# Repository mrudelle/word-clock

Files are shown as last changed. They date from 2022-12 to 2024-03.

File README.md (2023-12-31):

# Modular word-clock software for micropython

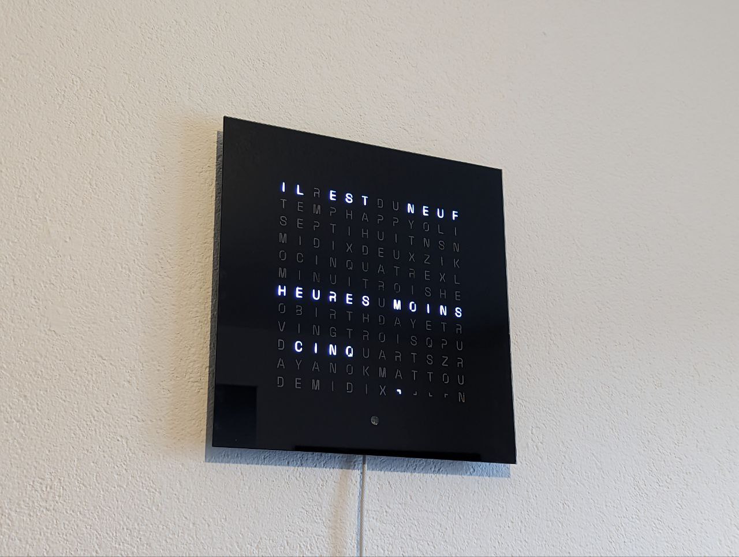
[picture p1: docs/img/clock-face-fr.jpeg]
Word clock


* Support the addition of new clock faces (other dimensions, language, layout,...). see `src/clock_face`
* Compatible with neopixel LED strips
* Custom designed PCB jumper to easily build the neopixel LED Matrix ([See /hardware/pcb_jumper](/hardware/pcb_jumper/))
* Light sensor based luminosity adjustment
* Create your own animations. see `src/rendering`
* Asynchronous implementation with asyncio

## Sample wiring with Pi Pico

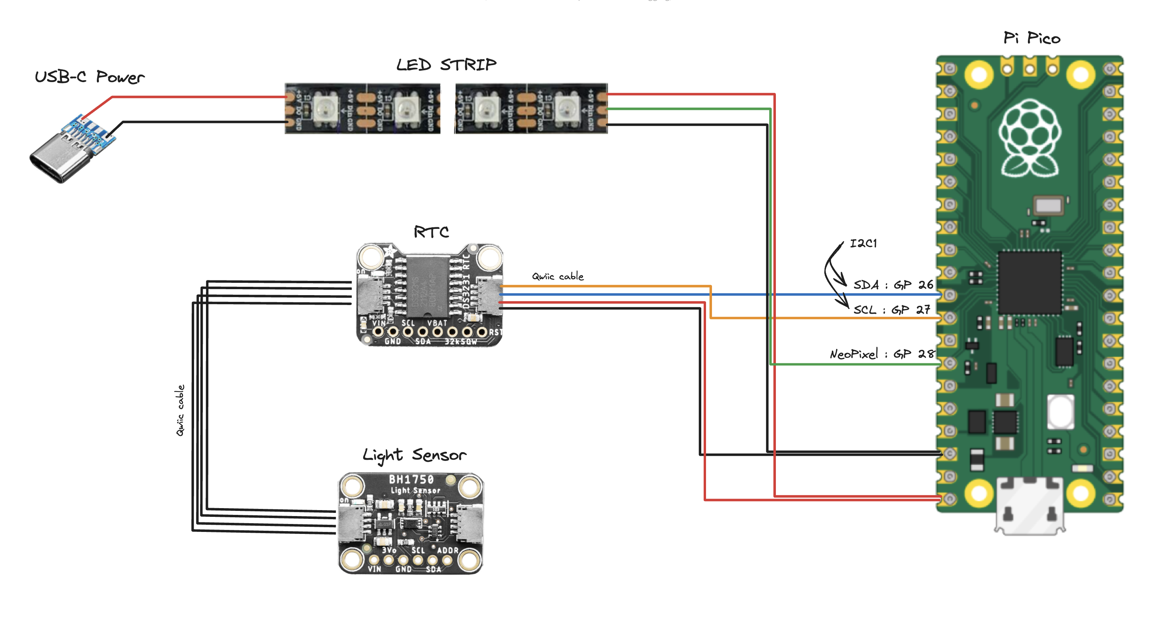
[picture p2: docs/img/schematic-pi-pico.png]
Word clock sample schematic with raspberry pi pico

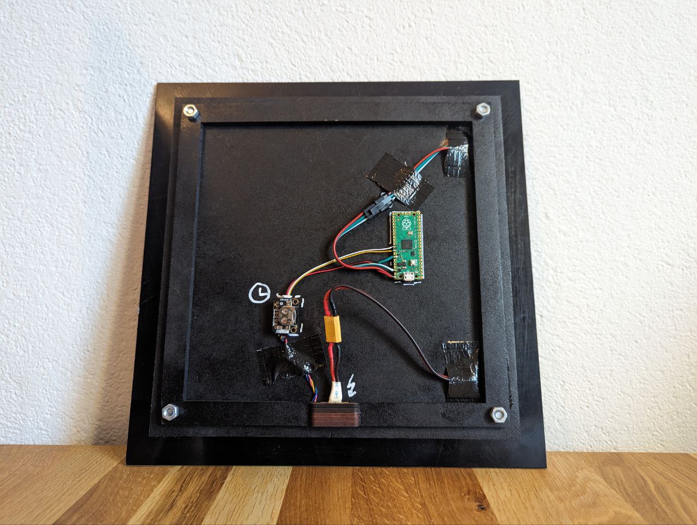
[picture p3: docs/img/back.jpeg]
Word clock wiring with raspberry pi pico

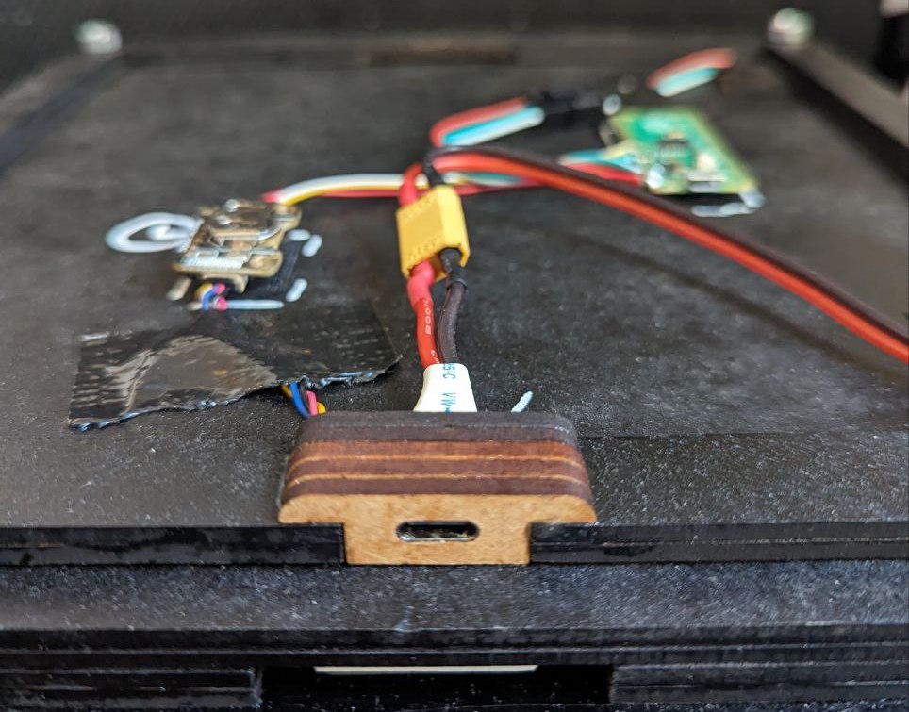
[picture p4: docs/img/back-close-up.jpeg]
Word clock usb socket


## Usage

### Install Requirements

```
python3 -m venv .venv
source .venv/bin/activate
pip3 install -r requirements-dev.txt
```

### Install code on rpi
Plug Raspbery Pi via USB,

```
mpremote cp -r src :
mpremote cp boot.py :.
mpremote cp main.py :.
```

Unplug and plug the clock to restart it.

### Set time

First, edit the time in `src/utils/set_date_time.py` so that it reflects the current time (plus a couple of seconds). Then run this command to set the time on the clock.

TODO: use the computer time to automatically set the clock time

```
mpremote run src/utils/set_date_time.py
```

### Dev

```
# run the main loop to catch any error
mpremote run main.py 
```

## Build

See [/hardware](/hardware/) for build infos and files

* Glass front with die-cut sticker on the back
* USB-C powered
* Frame laser cut in 4mm MDF
* Custom PCB board to wire the LED matrix

Font used for the clock face: [wordclock-stencil-mono](https://github.com/mrudelle/wordclock-stencil-mono)

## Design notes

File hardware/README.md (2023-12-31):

# Wordclock v2 Build

## BOM

* Raspberry pi pico
* RTC precision module DS3231 with stemma qt connectors (regular RTC modules like pcf8523 will drift by almost an hour per year)
* Light sensor BH1750 with stemma qt connectors
* 2 stemma qt connectors
* Neopixel led strip (eg. SK6812 or ws2814) 60 LED/m, 2.5m (important: not waterproof)
* USB-C breakout board
* Optional: XT30 or 60 connector
* 11 PCB jumper (or use 11*3 small cables) [See /hardware/pcb_jumper](pcb_jumper/)
* 3mm thick glass panel 30x30cm
* MDF (3mm) Board to cut all components
* 4x M6 bolts with cone-shaped head

## Build

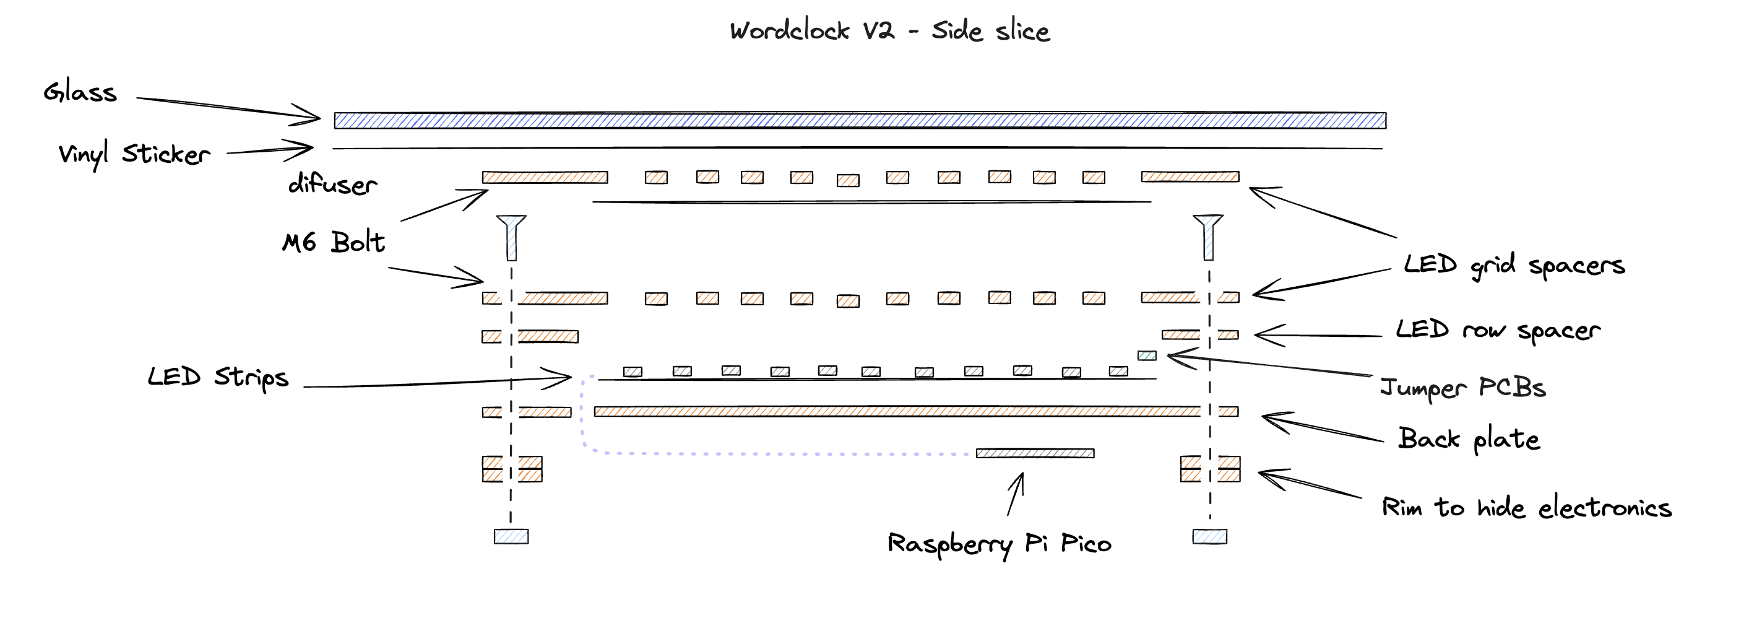
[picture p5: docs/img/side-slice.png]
Wordclock v2 side slice


The clock is made of a *glass panel* with a *die-cut vinyl sticker* on the back with the pattern of our clock. I ordered my glass panel from a glass shop nearby, prefer chamfered and polished edges. For the clock face I used this font [word-clock-stencil-mono](https://github.com/mrudelle/wordclock-stencil-mono). Pattern was cut on a cricut tracer. To apply the pattern I used the water technique and an credit card to squeeze all bubbles out. Longest part was taking out all the letters with a pair of tweezers (that's why the font is stencil).

On the vinyl is glued a lasercut MDF grid spacer. The vinyl was gently sanded to provide more grip for the glue.

A diffuser is placed on the spacer. I colored the diffuser with a black marker so that letters are stealth when not lit up. _Tip: mark the squares with a checker pattern to avoid the page to warp too much_

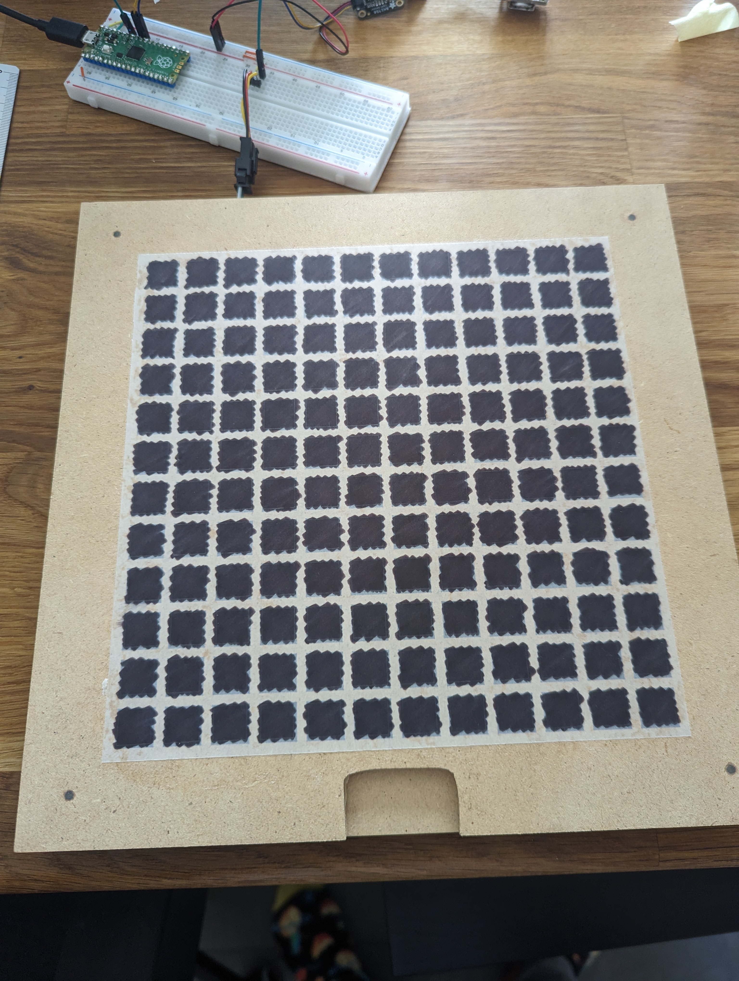
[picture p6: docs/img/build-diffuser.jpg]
Wordclock v2 diffuser


Another MDF grid spacer is placed on top (glued) with 4 cone-shaped head m6 screws. The screw will help hold the various layers together. The MDF grid spacer m6 holes are chamfered to hold on to the screws when glued to the vinyl. And the screws are flush with the spacer.

The next layer is an MDF LED row spacer.

Then the back plate, with LED taped on it, with the PCB jumpers soldered to recreate a long chain. I ordered 1.6mm thick custom designed PCB jumpers for cheap (from PCBway IIRC). With castelated holes to easily solder them onto the led strips. See [/hardware/pcb_jumper](pcb_jumper/).

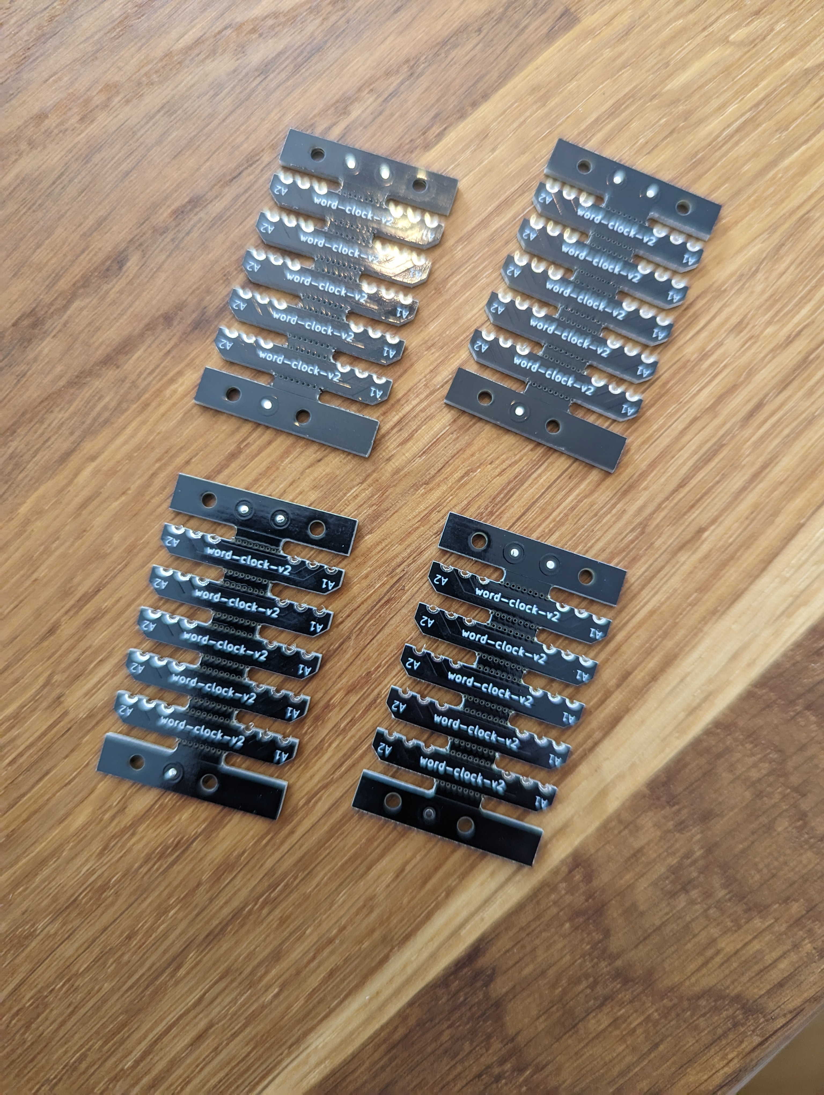
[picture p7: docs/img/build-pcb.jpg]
Wordclock v2 custom designed pcb

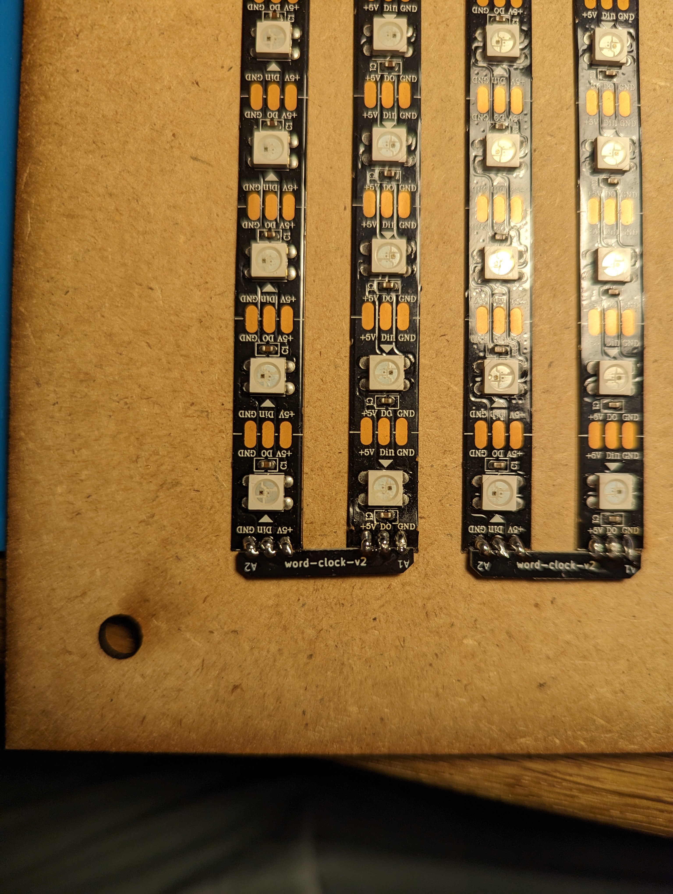
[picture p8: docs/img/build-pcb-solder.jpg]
Wordclock v2 jumper pcb soldering

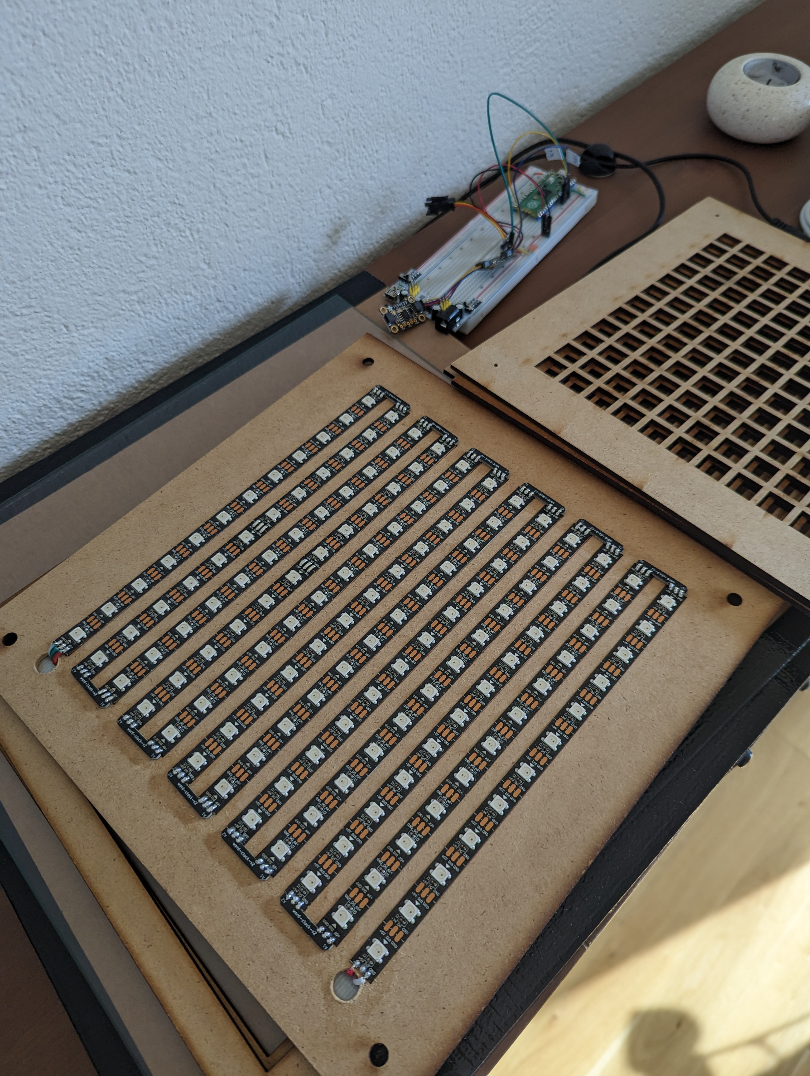
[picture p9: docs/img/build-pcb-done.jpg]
Wordclock v2 back plate assembled


On the back of that back plate goes all the electronics. Hidden by a rim that is screwed to the bolts and holds everything together. I painted the visible parts black to hide them a bit more when looking from the side.

Wordclock v2 back plate with electornics

Tip: do not tighten the screews too much, it might apply a localised negative pressure on the vinyl and start pealing it.

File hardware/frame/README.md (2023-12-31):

# Word clock v2 frame

Included:
* FreeCAD file
* DXF files for laser-cutting
    * `backplates_lasercut_v02.dxf` the main plates of the clock
        * The last backplate should not be cut through, just marked, to more easily place the LED Strips
    * `rim.dxf` Rim on the back to hide the electronics (has to be lasercut twice for a thicker rim)
        * These can be postprocessed to 1) fit the USB-C port if you like that option 2) create a notch in one of the plates to hang the clock
    * `USB_connector.dxf` parts to build a usbc socket
        * In hindsight, I would enlarge 4 of the five holes for the plug to make it easier to fit a soldered connector

Notes:
* Currently uses M6 bolts, I would recommend using smaller ones like m3

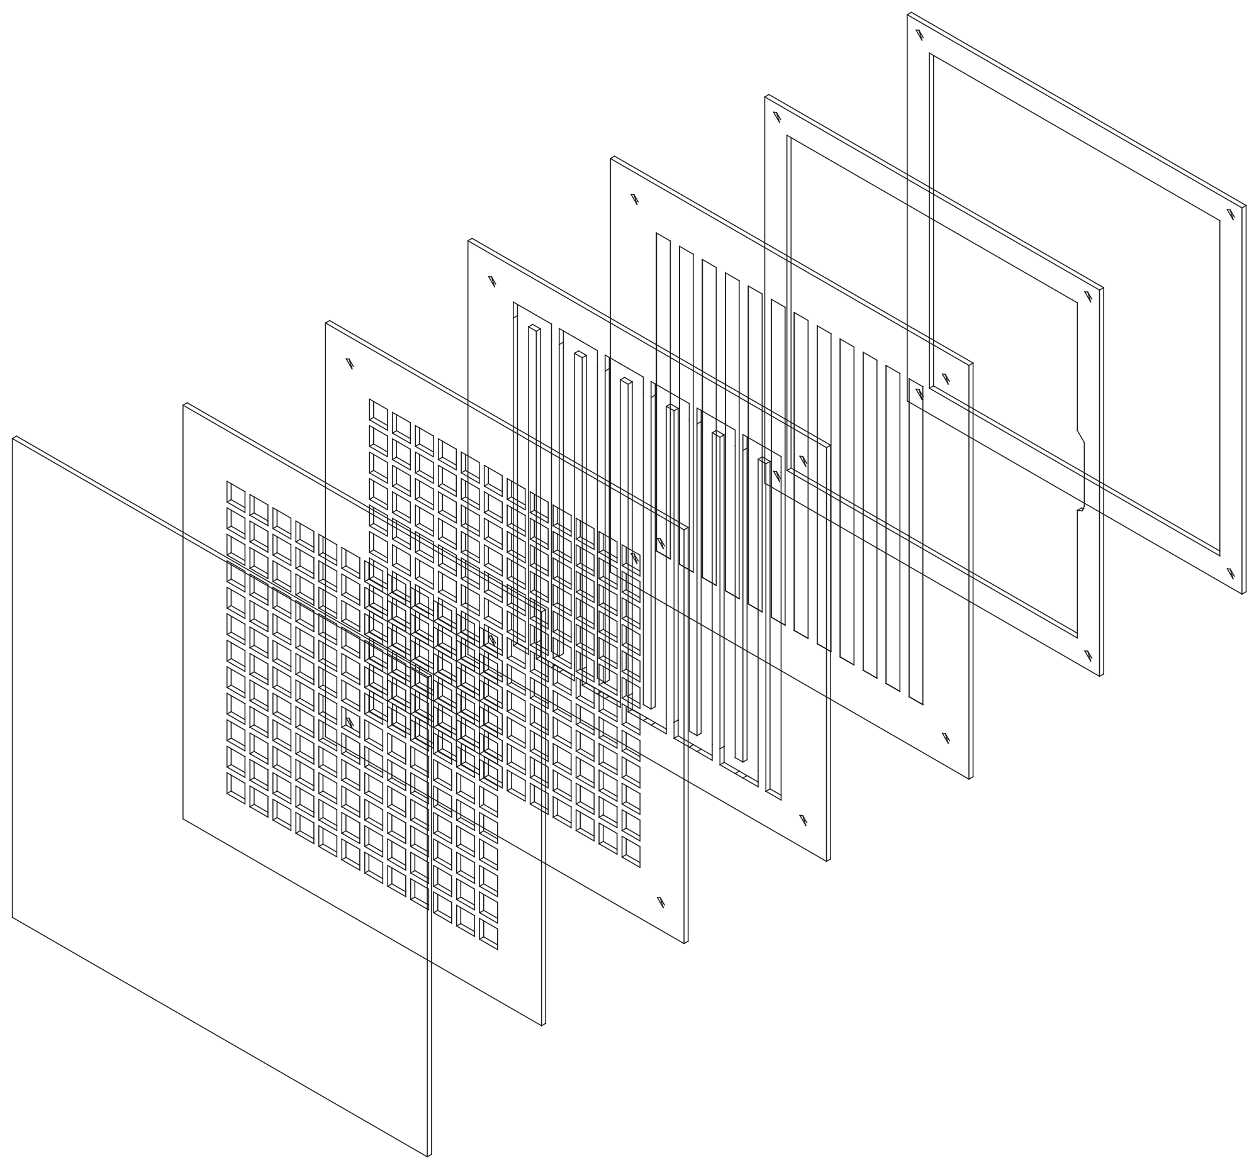
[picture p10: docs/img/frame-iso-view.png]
Word clock v2 frame iso view


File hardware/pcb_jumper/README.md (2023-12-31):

# Word clock v2 PCB Jumper 

Easily solder NeoPixel LED strips in a matrix. With a castellated PCB made for a 60 LED/m matrix spacing.

* Bigger traces (1mm) for 5V and GND to support higher currents
* KiCad and gerber files are available in this repository

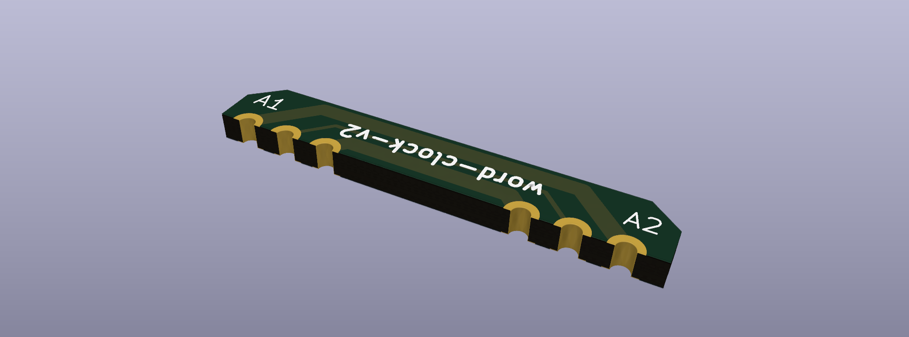
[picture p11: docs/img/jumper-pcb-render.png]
Word clock v2 jumper pcb render

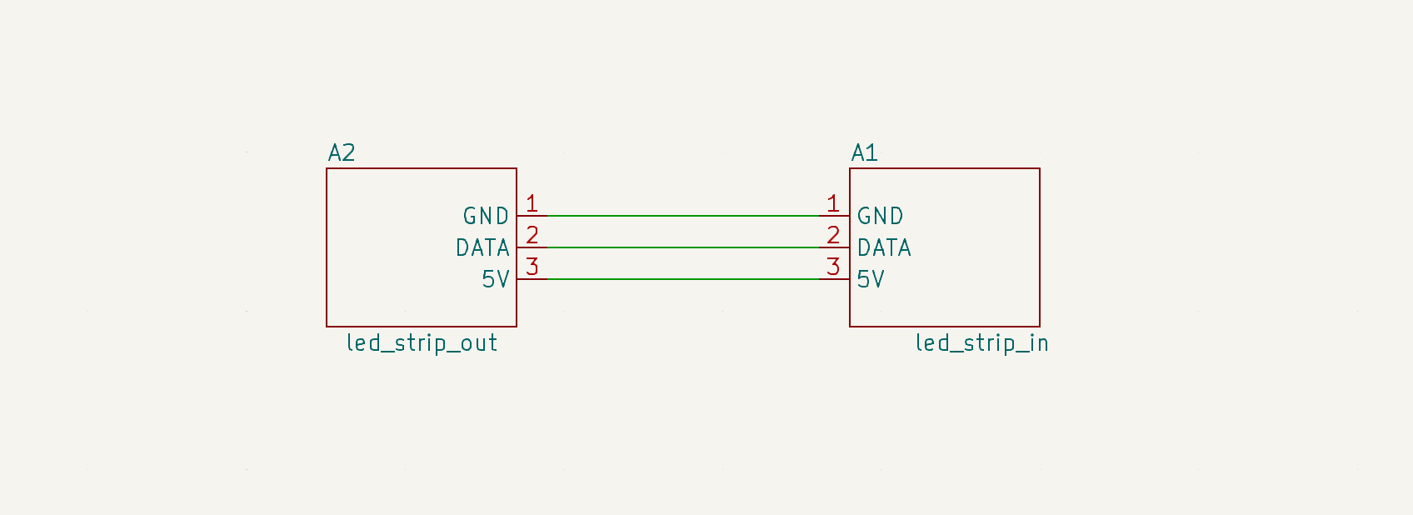
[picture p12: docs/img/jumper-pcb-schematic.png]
Word clock v2 jumper pcb schematic

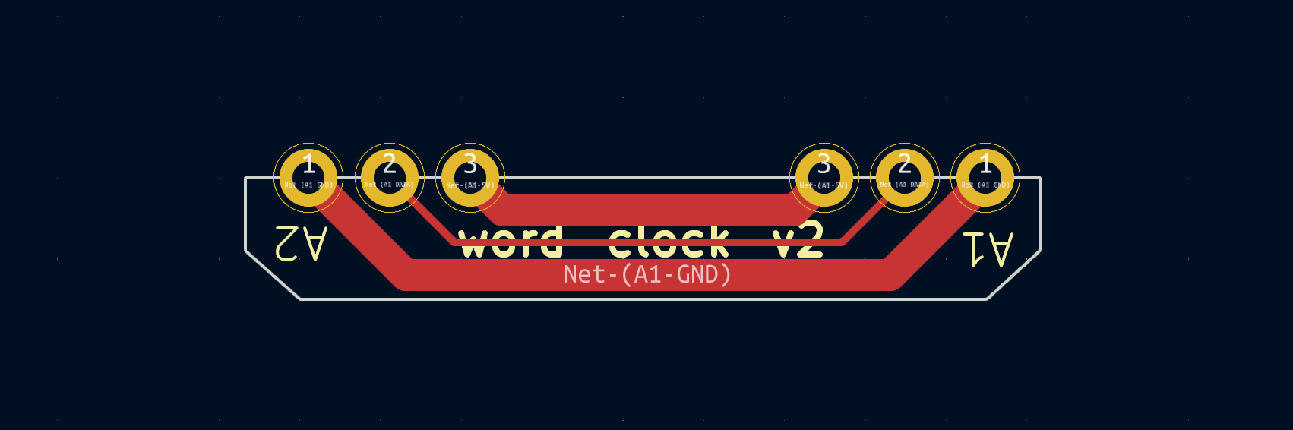
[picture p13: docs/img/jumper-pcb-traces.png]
Word clock v2 jumper pcb traces


Wordclock v2 jumper pcb soldering

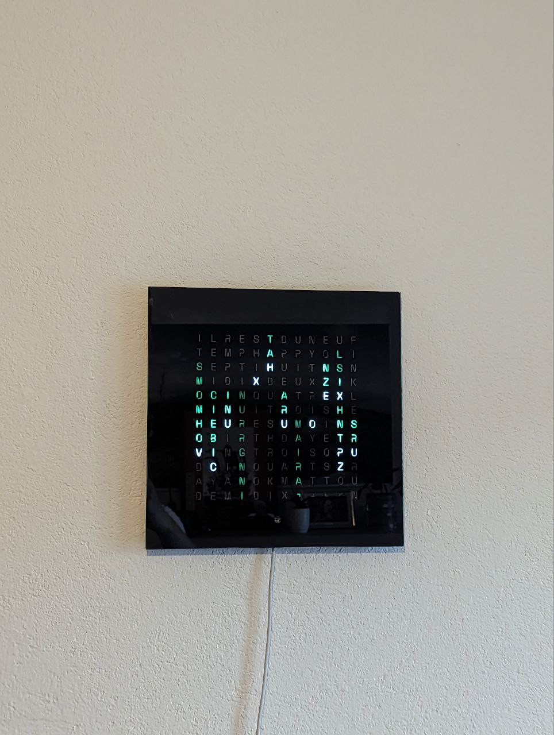
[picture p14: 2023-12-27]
docs/img/animation-matrix-code.jpeg

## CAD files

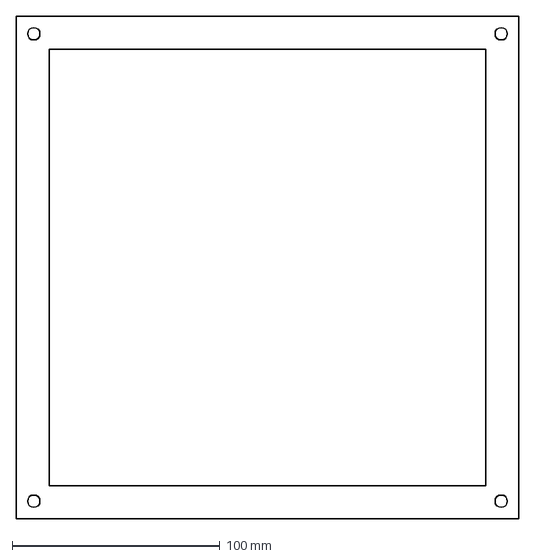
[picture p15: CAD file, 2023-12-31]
hardware/frame/rim.dxf
242.0 x 242.0 mm

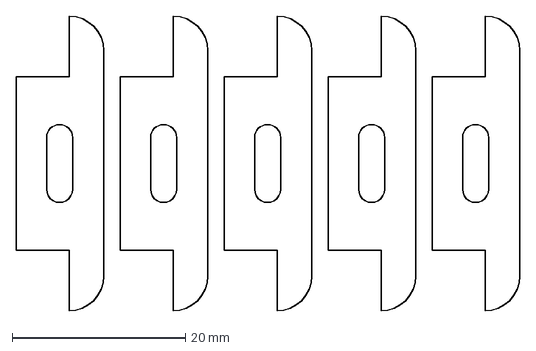
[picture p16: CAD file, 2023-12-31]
hardware/frame/USB_connector.dxf
58.1 x 34.0 mm

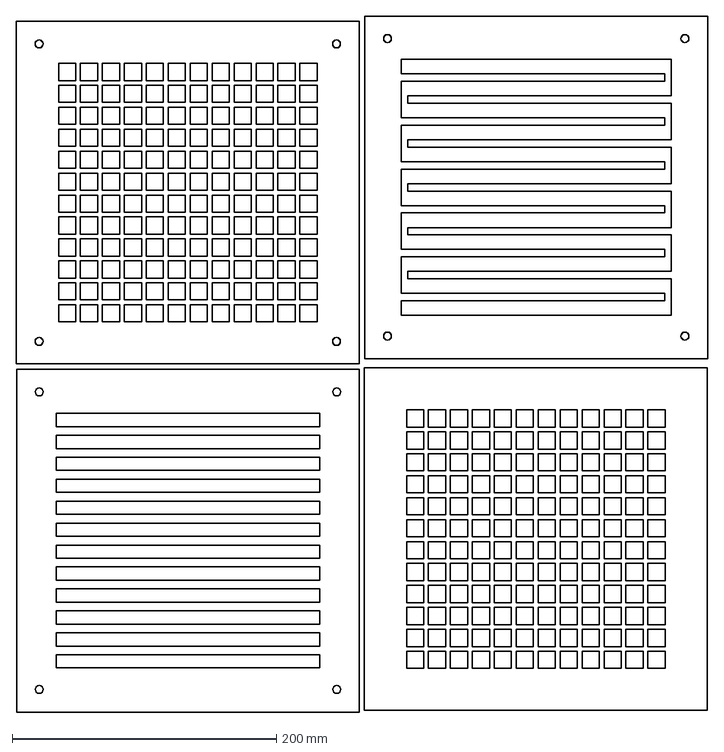
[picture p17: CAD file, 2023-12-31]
hardware/frame/backplates_lasercut_v02.dxf
522.7 x 526.5 mm

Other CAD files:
hardware/frame/WordclockV2.FCStd

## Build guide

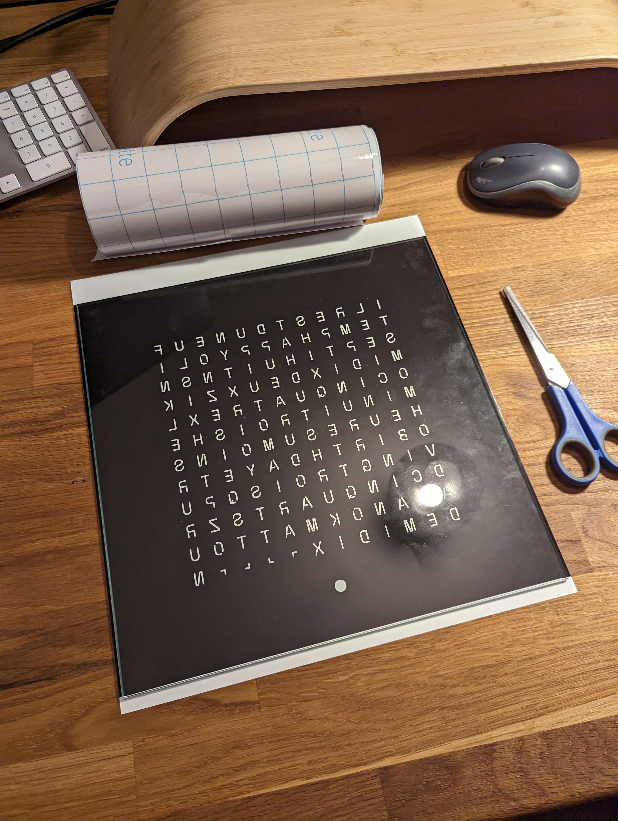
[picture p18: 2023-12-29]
docs/img/build-vinyl.jpg

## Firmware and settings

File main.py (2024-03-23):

import machine
from src.clock import Clock
from src.clock_face.word_clock import WordClockV1FR
from src.clock_face.word_clock_v2 import WordClockV2FR

IC2_SCL = 27
IC2_SDA = 26
LED_STRIP = 28

# Config Matt
CLOCK_FACE = WordClockV2FR()

# Config Pierre
# CLOCK_FACE = WordClockV1FR()


i2c_bus = machine.I2C(1, scl=machine.Pin(IC2_SCL), sda=machine.Pin(IC2_SDA))
clock = Clock(i2c_bus, CLOCK_FACE, led_strip_pin=LED_STRIP)
clock.run()

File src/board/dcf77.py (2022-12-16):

import machine
from time import ticks_ms, ticks_add, ticks_diff, sleep_ms


def _wait_until(some_ticks):
    sleep_ms(ticks_diff(some_ticks, ticks_ms()))


DCF77_COEF = [1, 2, 4, 8, 10, 20, 40, 80] 


class DCF77:

    def __init__(self, pin_number):
        self.pin = machine.Pin(pin_number, machine.Pin.IN)
    
    def wait_for_sync(self):
        """ 
        returns when a 59th second of sync is detected 
        returned value is the tick_ms at the start of the minute
        """

        check_period_ms = 50
        first_signal_acquired = False
        last_chirp = ticks_ms()
        next_check = ticks_add(last_chirp, check_period_ms)

        while True:
            _wait_until(next_check)
            
            if self.pin.value() == 1:
                last_chirp = ticks_ms()
                first_signal_acquired = True
                print('chirp')
            else:
                print('.', end='')
            
            if ticks_diff(ticks_ms(), last_chirp) > 1000 and first_signal_acquired:
                return ticks_ms()
            
            next_check = ticks_add(next_check, check_period_ms)
    
    def count_until(self, start_ms, end_ms, resolution_ms):
        count = 0
        next_check = ticks_add(start_ms, resolution_ms)

        while ticks_diff(end_ms, ticks_ms()) > 0:
            _wait_until(next_check)
            
            if self.pin.value() == 1:
                count += 1
                print('#', end='')
            else:
                print('.', end='')

            next_check = ticks_add(next_check, resolution_ms)
        
        return count

    def record_one_minute(self, minute_start, resolution_ms=50):

        seconds = []

        record_start = ticks_add(minute_start, 500)
        _wait_until(record_start)

        for s_i in range(59):

            record_start = ticks_add(record_start, 300)
            record_end = ticks_add(record_start, 300)
            seconds += [self.count_until(record_start, record_end, resolution_ms)]
            record_start = ticks_add(record_end, 400)
            
            print(f'    {s_i}: {seconds[s_i]}')
        
        return seconds
    
    def parse_minute(self, data, threshold):

        data_bin = [d >= threshold for d in data]

        def decode_int(bin):
            res = 0
            for i, b in enumerate(bin):
                if b:
                    res += DCF77_COEF[i]
            return res
        
        def check_parity(bin):
            res = 0
            for b in bin:
                if b:
                    res += 1
            return res % 2 == 0

        d_a1 = data_bin[16]
        d_cet = data_bin[17]
        d_cest = data_bin[18]
        d_a2 = data_bin[19]

        d_s = data_bin[20]

        minutes = decode_int(data_bin[21:28])
        hours = decode_int(data_bin[29:35])

        day = decode_int(data_bin[36:42])
        weekday = decode_int(data_bin[42:45])
        month = decode_int(data_bin[45:50])
        year = decode_int(data_bin[50:58]) + 2000  # safe bet

        m_check = check_parity(data_bin[21:29])
        h_check = check_parity(data_bin[29:36])
        date_check = check_parity(data_bin[36:59])

        checks = [m_check, h_check, date_check, d_s, d_cet != d_cest]  # not d_a1, not d_a2,

        return (checks, year, month, day, weekday, hours, minutes)
    
    def get_time(self):

        sync_tick = self.wait_for_sync()
        print('got a sync second')
        seconds = self.record_one_minute(sync_tick, resolution_ms=5)
        (checks, year, month, day, weekday, hours, minutes) = self.parse_minute(seconds, threshold=25)

        if False in checks:
            print(f'Extended checks failed: {checks}')
        
        if False in checks[0:2]:
            print(f'Failed time checks, {hours}:{minutes} {day}.{month}.{year} ({weekday})')
        else:
            print(f'Time: {hours}:{minutes} {day}.{month}.{year} ({weekday})')


if __name__ == "__main__":
    
    while True:
        DCF77(11).get_time()

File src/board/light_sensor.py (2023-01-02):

import utime
import uasyncio

class BH1750_I2C:
    """ Taken from https://github.com/PinkInk/upylib/tree/master/bh1750 """

    PWR_OFF = 0x00
    PWR_ON = 0x01
    RESET = 0x07

    # modes
    CONT_LOWRES = 0x13
    CONT_HIRES_1 = 0x10
    CONT_HIRES_2 = 0x11
    ONCE_HIRES_1 = 0x20
    ONCE_HIRES_2 = 0x21
    ONCE_LOWRES = 0x23

    def __init__(self, bus, addr=0x23) -> None:
        self.bus = bus
        self.addr = addr
        self.off()
        self.reset()
    
    def set_mode(self, mode):
        self.mode = mode
        self.bus.writeto(self.addr, bytes([mode]))

    def off(self):
        self.set_mode(self.PWR_OFF)

    def on(self):
        self.set_mode(self.PWR_ON)
    
    def reset(self):
        self.on()
        self.set_mode(self.RESET)
    
    def luminance(self, mode):
        # continuous modes
        if mode & 0x10 and mode != self.mode:
            self.set_mode(mode)
        # one shot modes
        if mode & 0x20:
            self.set_mode(mode)
        # earlier measurements return previous reading
        utime.sleep_ms(24 if mode in (BH1750_I2C.ONCE_LOWRES, BH1750_I2C.CONT_LOWRES) else 180)
        data = self.bus.readfrom(self.addr, 2)
        factor = 2.0 if mode in (BH1750_I2C.CONT_HIRES_2, BH1750_I2C.ONCE_HIRES_2) else 1.0
        return (data[0]<<8 | data[1]) / (1.2 * factor)
    
    def lux(self):
        return self.luminance(BH1750_I2C.ONCE_HIRES_2)
    
    async def async_luminance(self, mode):
        # continuous modes
        if mode & 0x10 and mode != self.mode:
            self.set_mode(mode)
        # one shot modes
        if mode & 0x20:
            self.set_mode(mode)
        # earlier measurements return previous reading
        await uasyncio.sleep_ms(24 if mode in (BH1750_I2C.ONCE_LOWRES, BH1750_I2C.CONT_LOWRES) else 180)
        data = self.bus.readfrom(self.addr, 2)
        factor = 2.0 if mode in (BH1750_I2C.CONT_HIRES_2, BH1750_I2C.ONCE_HIRES_2) else 1.0
        return (data[0]<<8 | data[1]) / (1.2 * factor)
    
    async def async_lux(self):
        return await self.async_luminance(BH1750_I2C.ONCE_HIRES_2)

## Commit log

2022-11-27 refactor buffer, prepare LED matrix rendering
2022-12-04 working version with micropython & pi pico
2022-12-04 added lght sensor lib
2022-12-16 dcf77 fixes & added matrix code
    [dcf77.py, main.py, matrix_code.py]
2022-12-22 cleanup, luminosity sensor & async
2022-12-22 Implement light timezone, fix bug in line generation
    [clock.py, debug.py, main.py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]
2023-12-27 Document wiring
2023-12-31 add pcb jumper
    [wordclock_pcb_jumber.kicad_pcb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]
2023-12-31 release 3D CAD model and DXF files
    [USB_connector.dxf, WordclockV2.FCStd, backplates_lasercut_v02.dxf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]
